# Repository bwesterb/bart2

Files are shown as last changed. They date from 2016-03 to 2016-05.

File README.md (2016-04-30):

Controller for the Bar T2
-------------------------

We replaced the mechanical pressure switch of the Pavoni Bart T2 coffee
machine with two thermometers, three microcontrollers and a raspberry pi.

See `avr/attiny13/ctrl.c` for the firmware of the two microcontrollers
responsible for switching the heater on and off depending on the
temperature.

The third micrcontroller lets the raspberry pi communicate with the
other microcontroller.  Its firmware can be found in `avr/attiny85/mux.c`.

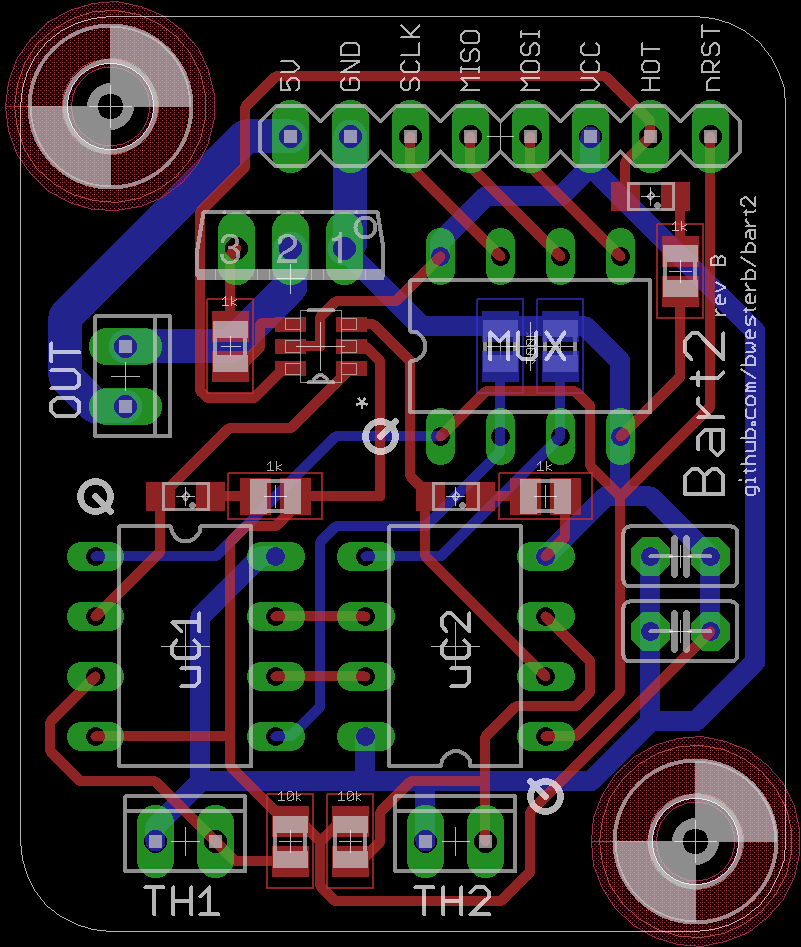
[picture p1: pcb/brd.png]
pcb


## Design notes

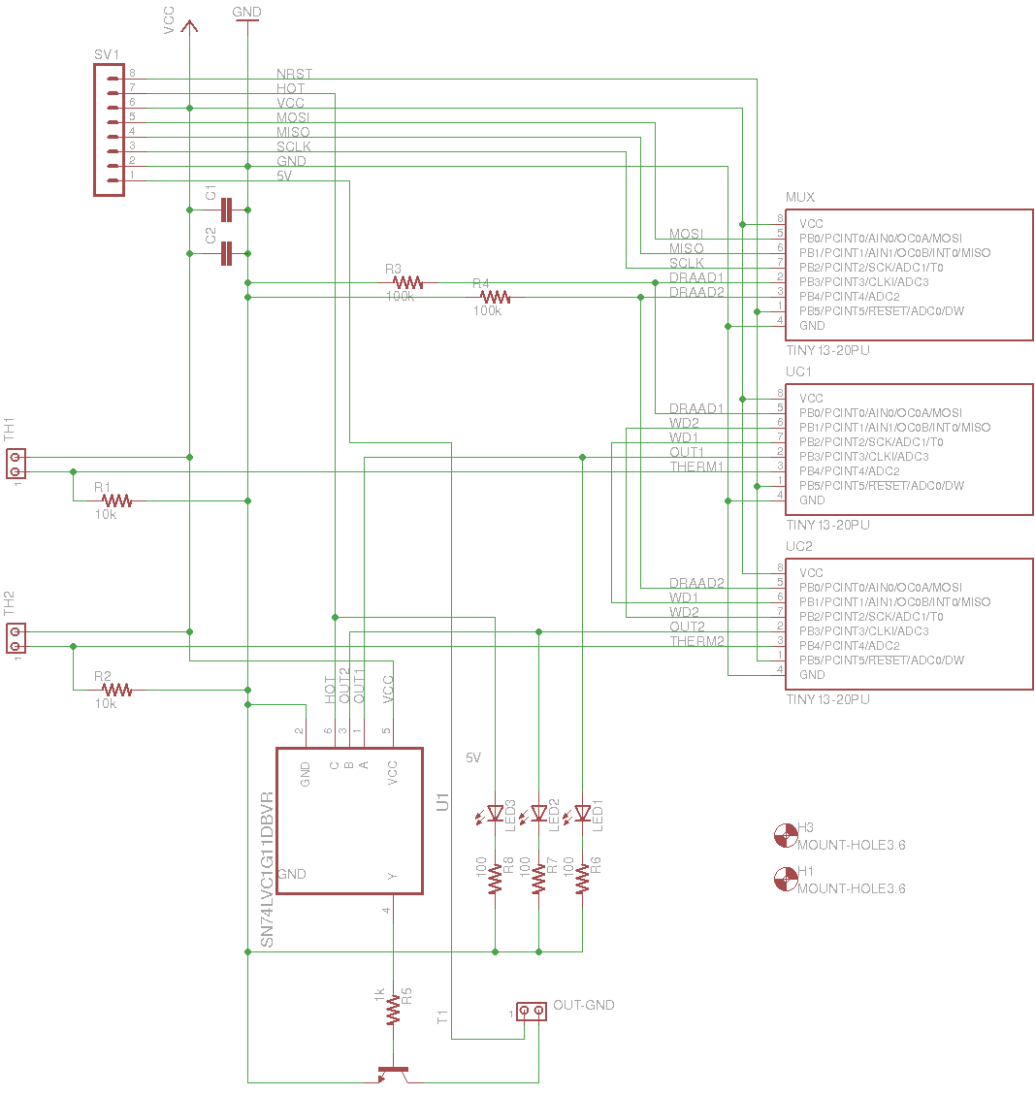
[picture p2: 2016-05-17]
pcb/sch.png

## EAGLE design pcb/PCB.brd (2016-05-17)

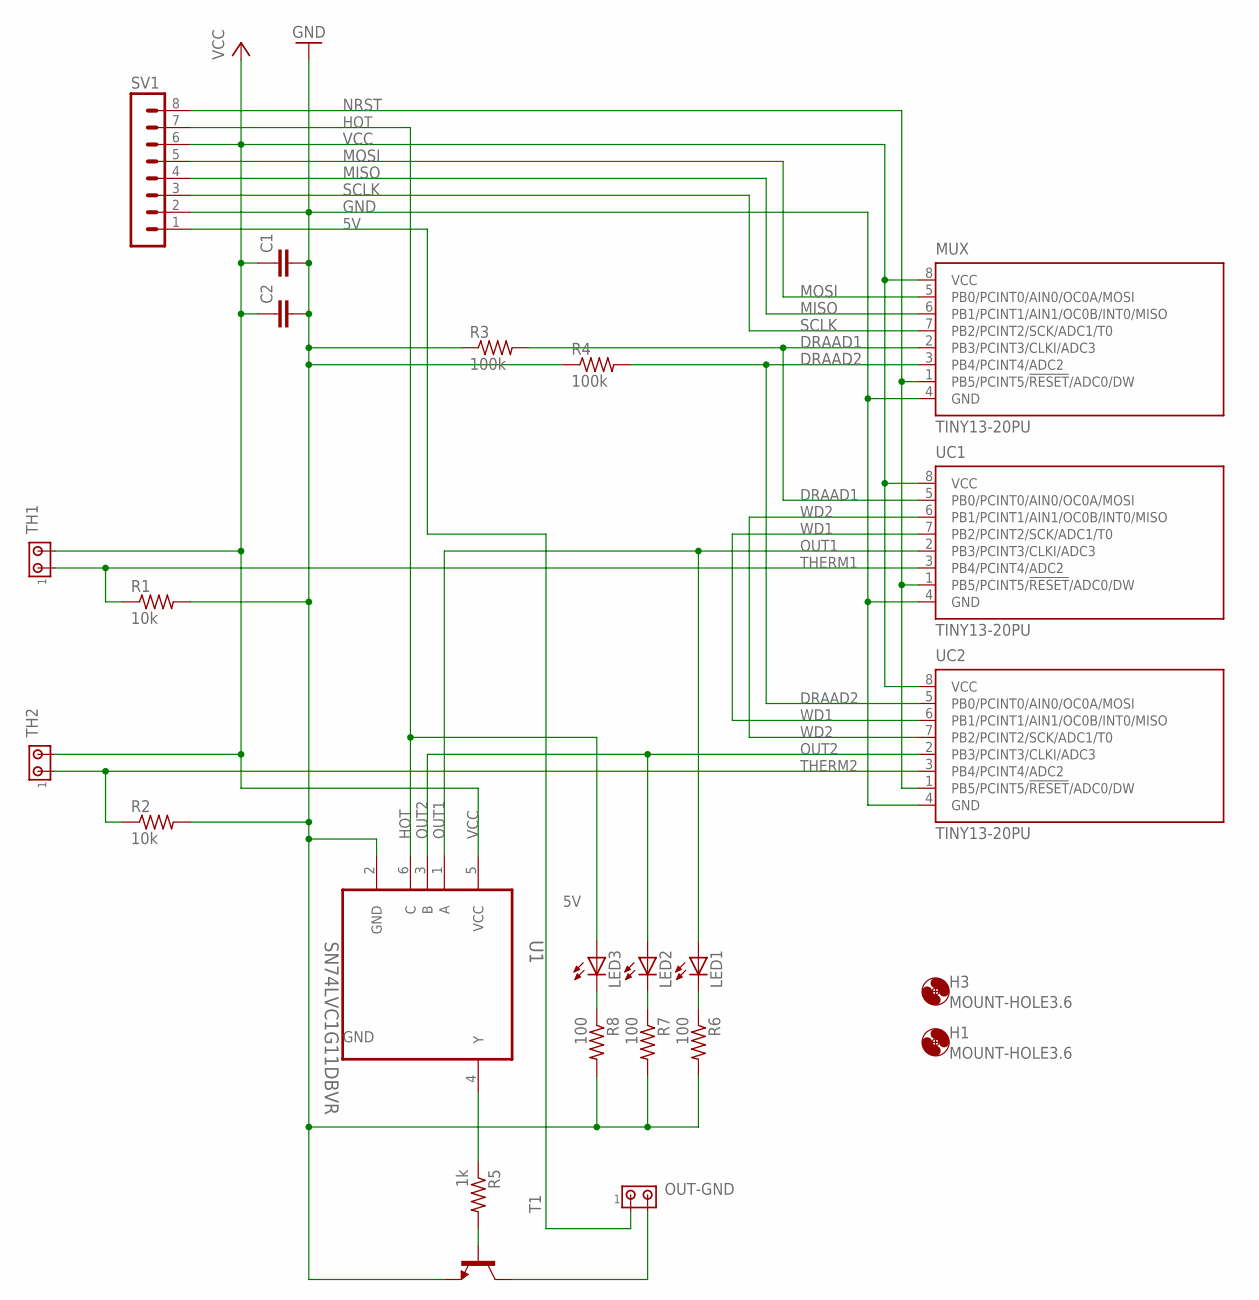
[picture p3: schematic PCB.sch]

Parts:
C1, C2: C2.5/2; C2.5-2
H1, H3: MOUNT-HOLE3.6; 3,6
LED1, LED2, LED3: LEDSML0805; SML0805
MUX: TINY13-20PU; DIL08
OUT-GND: MTA02-100; 10X02MTA
R1, R2: 10k; R0805
R3, R4: 100k; R0805
R5: 1k; R0805
R6, R7, R8: 100; R0805
SV1: MA08-1
T1: -NPN-TO126V; TO126V
TH1, TH2: MTA02-100; 10X02MTA
U1: SN74LVC1G11DBVR; SOT95P280X145-6N
UC1, UC2: TINY13-20PU; DIL08

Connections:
5V: OUT-GND.1, SV1.1
DRAAD1: MUX.2 (PB3/PCINT3/CLKI/ADC3), R3.2, UC1.5 (PB0/PCINT0/AIN0/OC0A/MOSI)
DRAAD2: MUX.3 (PB4/PCINT4/ADC2), R4.2, UC2.5 (PB0/PCINT0/AIN0/OC0A/MOSI)
GND: C1.2, C2.2, MUX.4 (GND), R1.2, R2.2, R3.1, R4.1, R6.2, R7.2, R8.2, SV1.2, T1.1 (E), U1.2 (GND), UC1.4 (GND), UC2.4 (GND)
HOT: LED3.A, SV1.7, U1.6 (C)
MISO: MUX.6 (PB1/PCINT1/AIN1/OC0B/INT0/MISO), SV1.4
MOSI: MUX.5 (PB0/PCINT0/AIN0/OC0A/MOSI), SV1.5
unnamed: OUT-GND.2, T1.2 (C)
unnamed: LED3.C, R8.1
unnamed: R5.1, U1.4 (Y)
unnamed: R5.2, T1.3 (B)
unnamed: LED2.C, R7.1
unnamed: LED1.C, R6.1
NRST: MUX.1 (PB5/PCINT5/!RESET!/ADC0/DW), SV1.8, UC1.1 (PB5/PCINT5/!RESET!/ADC0/DW), UC2.1 (PB5/PCINT5/!RESET!/ADC0/DW)
OUT1: LED1.A, U1.1 (A), UC1.2 (PB3/PCINT3/CLKI/ADC3)
OUT2: LED2.A, U1.3 (B), UC2.2 (PB3/PCINT3/CLKI/ADC3)
SCLK: MUX.7 (PB2/PCINT2/SCK/ADC1/T0), SV1.3
THERM1: R1.1, TH1.1, UC1.3 (PB4/PCINT4/ADC2)
THERM2: R2.1, TH2.1, UC2.3 (PB4/PCINT4/ADC2)
VCC: C1.1, C2.1, MUX.8 (VCC), SV1.6, TH1.2, TH2.2, U1.5 (VCC), UC1.8 (VCC), UC2.8 (VCC)
WD1: UC1.7 (PB2/PCINT2/SCK/ADC1/T0), UC2.6 (PB1/PCINT1/AIN1/OC0B/INT0/MISO)
WD2: UC1.6 (PB1/PCINT1/AIN1/OC0B/INT0/MISO), UC2.7 (PB2/PCINT2/SCK/ADC1/T0)

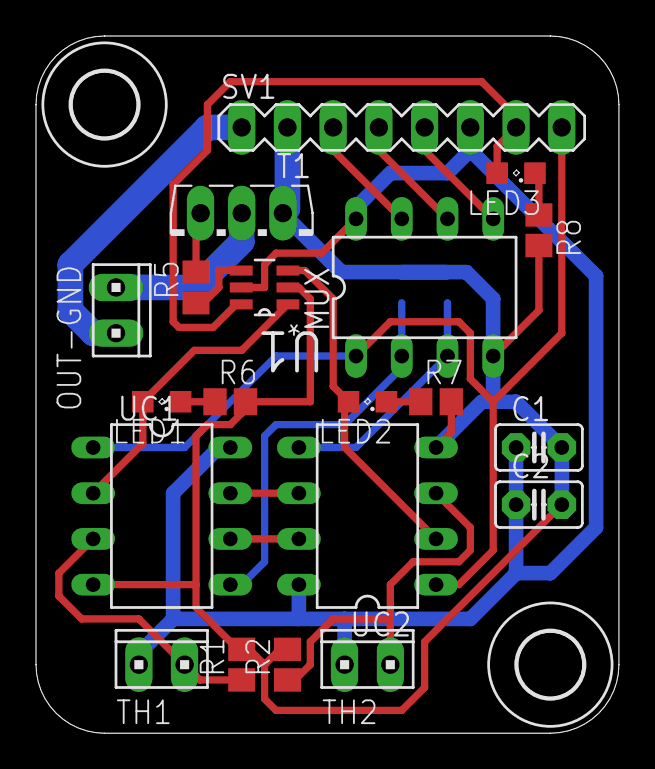
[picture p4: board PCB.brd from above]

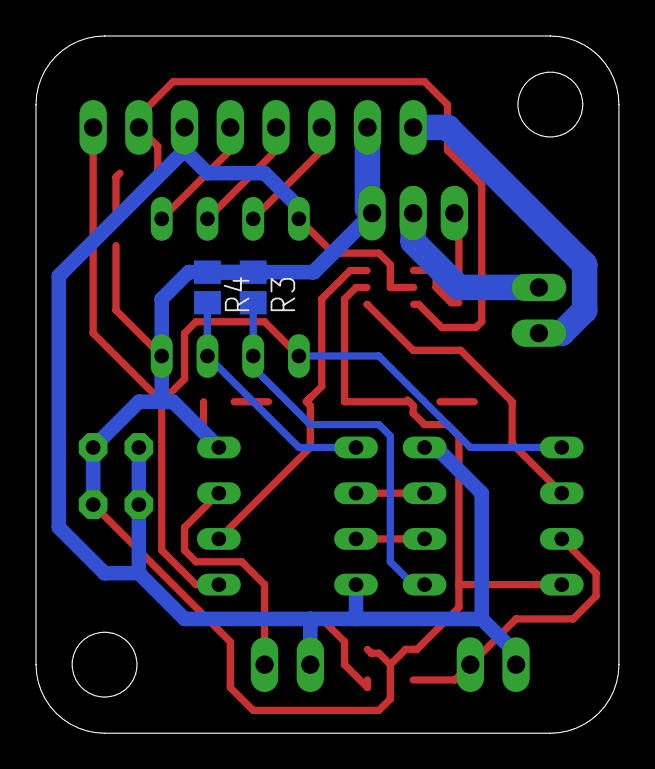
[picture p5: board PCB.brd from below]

Board: 2 copper layers, 32.4 x 38.7 mm, 24 parts (2 on the bottom side), 22 nets.

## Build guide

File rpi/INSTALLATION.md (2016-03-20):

The configuration of the rpi is managed using salt. This is how to bootstrap it.

1. Write raspbian lite to SD-card
2. Boot rPi and log in with user `pi` (password `raspberry`)
3. Change `/etc/wpa_supplicant/wpa_supplicant.conf` and run
   `systemctl restart networking` to get WiFi.
4. Run `raspi-config` and check everything.  Do not forget to enable SSH and SPI
   *and* to disable Serial login.  `reboot`.
5. Login via SSH.  Set `authorized_keys` on root. Delete the pi user. Scramble
   root password.
6. `apt-get update`
7. `apt-get install git salt-minion`
8. set `file_client: local` and `state_verbose: False` in `/etc/salt/minion`
9. `cd srv && git clone git://github.com/bwesterb/bart2`
10. `ln -s /srv/bart2/rpi/salt /srv/salt`
11. `salt-call state.highstate`

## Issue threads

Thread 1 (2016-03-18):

attiny13 frequency seems to be ~1.17MHz at 3.3V

bwesterb, 2016-03-18:
What is it exactly?  Does it vary?  Can we stabilise it?

bwesterb, 2016-03-19:
Default is 1.2MHz.  See §6.2.2 of docs.

bwesterb, 2016-03-22:
Varies quite a bit, actually.  Instead of UART, we'll use SPI, which has an external clock.

Closed 2016-03-19.

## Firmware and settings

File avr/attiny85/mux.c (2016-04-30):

// Firmware for the MUX ATTINY85 microcontroller.
//
// The MUX is connected to the rPi and the two microcontrollers that actually
// measure the temperature and determine whether to switch on the heaters
// of the coffee machine.
//
// The job of the MUX uC is to transfer messages to and from the two
// other uCs to the rPi.
//
// The MUX is connected to the rPi using a 3-wire SPI connection in mode 01
// with a baudrate of ~10kHz.
//
// There is a single wire from the MUX to each of the other uCs.  With this
// single wire the uC and the MUX can communicate in half-duplex using a
// variation on the "one-wire protocol", we call "draad".  See XXX
//
// XXX send status

#include "common.h"

// Pinout
#define PIN_SPI_MOSI   DDB0
#define PIN_SPI_MISO   DDB1
#define PIN_SPI_CLOCK  DDB2
#define PIN_DRAAD1     DDB3
#define PIN_DRAAD2     DDB4

register unsigned long spi_tx_buffer asm("r10"); // r10, r11, r12, r13
register byte spi_tx_buffer_size asm("r14");    // XXX only need 5 bits

volatile unsigned long draad_tx_buffer[2] = {0,0};
volatile byte draad_tx_buffer_size[2] = {0,0};

unsigned long draad_rx_buffer[2] = {0,0};
byte draad_rx_buffer_size[2] = {0,0};


struct status {
    byte draad_tx_overflow : 1;
    byte spi_rx_overflow : 1;
};

register struct status status asm("r15");

#define SPI_RX_BUFFER_MAX   8       // max size of the SPI rx buffer
byte spi_rx_buffer[SPI_RX_BUFFER_MAX];
byte spi_rx_buffer_size asm("r16");
byte spi_rx_buffer_offset asm("r17");

void main(void) __attribute__ ((noreturn));

void main(void)
{
    byte spi_frame_body_bits_to_read = 0;
    byte spi_frame_body_size = 0;
    long spi_frame_body;
    byte spi_frame_who;

    full_speed_clock();

    spi_tx_buffer = 0;
    spi_tx_buffer_size = 0;

    spi_rx_buffer_size = 0;
    spi_rx_buffer_offset = 0;

    status.draad_tx_overflow = 0;
    status.spi_rx_overflow = 0;

    // Set up pins and interrupts for SPI.
    DDRB |= _BV(PIN_SPI_MISO);  // MISO (for SPI) is output

    // Set up universal serial interface
    USICR |= _BV(USIWM0) | _BV(USICS1) | _BV(USICS0) // SPI mode 01
          | _BV(USIOIE);   // with overflow interrupt.

    sei();  // enable interrupts

    // We will loop and either
    //  (1) poll the first uC,
    //  (2) poll the second uC,
    //  (3) prepare the data to be send over SPI or
    //  (4) parse the data we received over SPI.
    // We process the SPI data in the main loop such that we don't spend
    // too much time in interrupt handlers, which would mess with the timing
    // on the draad.

    byte who = 0; // which uC is being polled?

    for(;;) {
        who = 1 - who;
        
        // Interpret SPI rx buffer if it's not empty
        while (spi_rx_buffer_size > 0) {
            byte spi_byte_received;

            ATOMIC_BLOCK(ATOMIC_FORCEON)
            {
                spi_byte_received = spi_rx_buffer[spi_rx_buffer_offset];
                spi_rx_buffer_size--;
                spi_rx_buffer_offset = (spi_rx_buffer_offset + 1)
                                                % SPI_RX_BUFFER_MAX;
            }

            // Are we in the middle of receiving a frame?
            if (spi_frame_body_bits_to_read > 0) {
                if (spi_frame_body_bits_to_read < 8)
                    spi_frame_body_bits_to_read = 0;
                else
                    spi_frame_body_bits_to_read -= 8;
                spi_frame_body |= (spi_byte_received
                                    << spi_frame_body_bits_to_read);

                if (spi_frame_body_bits_to_read > 0)
                    continue;

                // We received the whole frame.  Send it over draad.
                if (spi_frame_who > 1)
                    continue;

                // Check for overflow
                if (draad_tx_buffer_size[spi_frame_who]
                            + spi_frame_body_size > 32) {
                    status.draad_tx_overflow = 1;
                    continue;
                }

                // Again note that we can't be interrupted here.
                draad_tx_buffer[spi_frame_who] |= (spi_frame_body
                                        << draad_tx_buffer_size[spi_frame_who]);
                draad_tx_buffer_size[spi_frame_who] += spi_frame_body_size;
                continue;
            }

            // Either there is no frame, or we are at the start of a frame.
            // Is there a frame?
            if (!(spi_byte_received & 128))
                continue;  // there is no frame

            // Start of a new frame.  Parse the header
            spi_frame_body_size = (spi_byte_received >> 2) & 31;
            spi_frame_body_bits_to_read = spi_frame_body_size;
            spi_frame_who = (spi_byte_received) & 3;
            spi_frame_body = 0;
        }

        // Fill SPI tx buffer if it's empty
        if (spi_tx_buffer_size == 0 && draad_rx_buffer_size[who] > 0) {
                byte n_bits_to_send = draad_rx_buffer_size[who];
                if (n_bits_to_send > 24)
                    n_bits_to_send = 24;
            ATOMIC_BLOCK(ATOMIC_FORCEON)
            {
                spi_tx_buffer = 128 | (n_bits_to_send << 2) | who
                                  | (draad_rx_buffer[who] << 8);
                spi_tx_buffer_size = 8 + n_bits_to_send;
            }
            draad_rx_buffer_size[who] -= n_bits_to_send;
            draad_rx_buffer[who] >>= n_bits_to_send;
        }

        byte pin = who == 0 ? PIN_DRAAD1 : PIN_DRAAD2;

        if (draad_tx_buffer_size[who] > 0) {
            byte to_send;

            // Fetch the bit to send
            ATOMIC_BLOCK(ATOMIC_FORCEON)
            {
                to_send = draad_tx_buffer[who] & 1;
                draad_tx_buffer[who] >>= 1;
                draad_tx_buffer_size[who]--;
            }

            // Send the bit
            PORTB |= _BV(pin);
            if (to_send)
                _delay_us(DRAAD_DELAY * 3 - DRAAD_PULLDOWN_TIME);
            else
                _delay_us(DRAAD_DELAY * 2 - DRAAD_PULLDOWN_TIME);

            PORTB &= ~_BV(pin);
            if (to_send)
                _delay_us(DRAAD_DELAY * 1 + DRAAD_PULLDOWN_TIME);
            else
                _delay_us(DRAAD_DELAY * 2 + DRAAD_PULLDOWN_TIME);

            continue;
        }

        // Is our buffer empty enough to receive something from the uC?
        if (draad_rx_buffer_size[who] == 32)
            continue;

        byte received = 0;
        PORTB |= _BV(pin);
        _delay_us(DRAAD_DELAY - DRAAD_PULLDOWN_TIME);

        PORTB &= ~_BV(pin);
        _delay_us(DRAAD_DELAY + DRAAD_PULLDOWN_TIME);

        if (!(PINB & _BV(pin))) {
            _delay_us(DRAAD_DELAY * 2);
            continue;  // No reply
        }

        _delay_us(DRAAD_DELAY);
        if (PINB & _BV(pin))
            received = 1;

        draad_rx_buffer[who] |= (received << draad_rx_buffer_size[who]);
        draad_rx_buffer_size[who]++;
        _delay_us(DRAAD_DELAY);
    }
}

// Interrupt handlers.

// Called when the USI unit just received data over SPI.  We store the data in
// a buffer.  Also we provide the USI unit with the byte to send for the next
// cycle.
ISR(USI_OVF_vect)
{
    if (spi_rx_buffer_size == SPI_RX_BUFFER_MAX) {
        status.spi_rx_overflow = 1;
    } else {
        byte i = (spi_rx_buffer_offset + spi_rx_buffer_size
                        ) % SPI_RX_BUFFER_MAX;
        spi_rx_buffer[i] = USIBR;
        spi_rx_buffer_size++;
    }

    if (spi_tx_buffer_size == 0) {
        USIDR = 0;
        goto done;
    }

    USIDR = spi_tx_buffer & 255;  // next byte to send

    spi_tx_buffer >>= 8;

    if (spi_tx_buffer_size < 8)
        spi_tx_buffer_size = 0;
    else
        spi_tx_buffer_size -= 8;

done:
    USISR |= _BV(USIOIF);  // clear interrupt
}

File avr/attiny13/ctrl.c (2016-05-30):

// Firmware for the uC1 and uC2 ATTINY13 microcontroller.
//
// Each of the uCs measures the temperature of the kettle and decides
// whether to turn on the boiler.  The uCs are connected to a third
// uC, the MUX, via a single wire.  See XXX
//
// XXX check whether temperature increase is within reasonable bounds when
//      the heater is turned on --- this is to prevent the boiler from heating
//      an (half-)empty boiler.

#include "common.h"

// Pinout
#define PIN_DRAAD      DDB0
#define PIN_WATCH_IN   DDB1
#define PIN_WATCH_OUT  DDB2
#define PIN_GO         DDB3
#define PIN_THERM      DDB4

// Limits on tempearture
#define TEMP_TARGET         790     // Heat if temp is below this
#define TEMP_LOWER_BOUND    26      // go into error mode if temp is below this
#define TEMP_UPPER_BOUND    980     // go into error mode if temp is above this

// We add 32 measurements and to get a neat average.  adc_accum cotains
// the partial sums of the current measurements and adc_cnt the amount we
// have performed.
register unsigned int adc_accum asm("r2");  // r2, r3
register byte adc_cnt asm("r4");
register byte watch_in_changed asm("r5");

struct status {
    unsigned int temperature : 10;
    byte heating : 1;
    byte ok : 1;
    byte temp_way_too_low : 1;
    byte temp_way_too_high : 1;
    byte other_uC_not_responding : 1;
};

struct status status;

void main(void) __attribute__ ((noreturn));

void main(void)
{
    full_speed_clock();

    // Initialize variables
    unsigned long draad_tx_buffer = 0;
    byte draad_tx_buffer_size = 0;

    adc_accum = 0;
    adc_cnt = 0;
    watch_in_changed = 0;

    status.heating = 0;
    status.ok = 1;
    status.temperature = 0;
    status.temp_way_too_low = 0;
    status.temp_way_too_high = 0;
    status.other_uC_not_responding = 0;

    // Set up watch timer (~18Hz)
    TCCR0B |= _BV(CS00) | _BV(CS02);  // enable clock --- prescale by 1024
    TIMSK0 |= _BV(TOIE0);        // enable clock overflow interrupt

    // Set up pins and interrupts for SPI.
    DDRB |= _BV(PIN_WATCH_OUT);  // Set WATCH_OUT to an output pin
    DDRB |= _BV(PIN_GO);         // Set GO to an output pin

    // Enable the ADC
    ADCSRA |= (1 << ADPS1) | (1 << ADPS2) | (1 << ADEN) | (1 << ADIE);
    ADMUX |= (1 << MUX1);  // ADC2 (PB4)

    PCMSK |= 1 << PCINT1;   // interrupt on WATCH_IN
    GIMSK |= 1 << PCIE;     // enable pin-change interrupts

    sei();  // enable interrupts

    ADCSRA |= (1 << ADSC);  // start first ADC conversion

    PINB |= _BV(PIN_WATCH_OUT);  // let other uC know the ADC is running

    // XXX make protocol on draad more flexible.  I.e. to set THERM_* runtime.
    for (;;) {
        // Wait until the mux pulls the draad high
        while (!(PINB & _BV(PIN_DRAAD)));

        _delay_us(DRAAD_DELAY * 1.25);

        // Is master sending a write(0) or write(1)?
        // If so, see what the master is writing.
        if (PINB & _BV(PIN_DRAAD)) {
            byte received = 0;

            _delay_us(DRAAD_DELAY * 1.50);

            if (PINB & _BV(PIN_DRAAD))
                received = 1;

            // XXX here we could handle more complex incoming messages ---
            // for now we'll just send our status message everytime we
            // get any incoming bit 1.
            if (draad_tx_buffer_size == 0 && received) {
                draad_tx_buffer = *((unsigned long*)(&status));
                draad_tx_buffer_size = 16;
            }

            while (PINB & _BV(PIN_DRAAD));

            _delay_us(DRAAD_DELAY * 0.25);
            continue;
        }

        // Master sends a read, send a bit if we have one to send.
        if (draad_tx_buffer_size == 0) {
            _delay_us(DRAAD_DELAY * 2.25);
            continue;
        }

        PORTB |= _BV(PIN_DRAAD);

        byte bit = !!(draad_tx_buffer & 1);
        draad_tx_buffer_size--;
        draad_tx_buffer >>= 1;

        if (bit)
            _delay_us(DRAAD_DELAY * 2 - DRAAD_PULLDOWN_TIME);
        else
            _delay_us(DRAAD_DELAY - DRAAD_PULLDOWN_TIME);

        PORTB &= ~_BV(PIN_DRAAD);
        _delay_us(DRAAD_DELAY * 0.25 + DRAAD_PULLDOWN_TIME);
    }
}

// ADC conversion is ready interrupt.
// XXX is the interrupt handler fast enough to not disturb draad communication?
ISR(ADC_vect)
{
    adc_accum += ADCW;
    adc_cnt++;

    if (adc_cnt == 32) {
        unsigned int temp = adc_accum >> 5;

        PINB |= _BV(PIN_WATCH_OUT);  // let other uC know the ADC is running

        status.temperature = temp;
        adc_accum = 0;
        adc_cnt = 0;

        if (temp <= TEMP_LOWER_BOUND) {
            status.ok = 0;
            status.temp_way_too_low = 1;
            status.heating = 0;
            PORTB &= ~_BV(PIN_GO);
        } else if (temp >= TEMP_UPPER_BOUND) {
            status.ok = 0;
            status.heating = 0;
            status.temp_way_too_high = 1;
            PORTB &= ~_BV(PIN_GO);
        } else if (!status.ok) {
        } else if (temp < TEMP_TARGET) {
            PORTB |= _BV(PIN_GO);
            status.heating = 1;
        } else  {
            PORTB &= ~_BV(PIN_GO);
            status.heating = 0;
        }
    }

    ADCSRA |= (1 << ADSC);
}

// Watchdog pin changed value.
ISR(PCINT0_vect)
{
    watch_in_changed = 1;
}

// Timer overflowed
ISR(TIM0_OVF_vect)
{
    // XXX grace period during start-up?
    if (!watch_in_changed) {
        // Other uC did not respond in time
        status.ok = 0;
        status.heating = 0;
        status.other_uC_not_responding = 1;
        PORTB &= ~_BV(PIN_GO);
        return;
    }

    watch_in_changed = 0;
}

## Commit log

2016-03-22 spitherm: test firmware that measures voltage on pin and sends over SPI
2016-03-22 Adapt blink just to blink LED and left-over pin
    With blink we can measure the frequency of the uC
2016-03-25 Added pcb
    [PCB.brd, PCB.sch]
2016-03-25 Added pictures of pcb
2016-03-28 Complete and fix mux. Decrease size.
    [mux.c]
2016-03-29 PCB image
2016-04-09 avr: add test for AVR timer
2016-04-09 ctrl: fix timer code
    [ctrl.c]
2016-04-10 avr: add mirror test fw to determine 0 -> 1 voltage
2016-04-16 mux: decode SPI frames
2016-04-17 attiny85: SPI test
2016-04-30 Two more bugs in the mux
    [mux.c]
2016-04-30 work on bart2d: spi
2016-05-01 more work on the spi interface
2016-05-10 Updated pcb
    [PCB.brd, PCB.sch]
2016-05-17 changes Muxi SPI speedHz to a power of 2 to support RPI mark 1
2016-05-30 ctrl: bounds for 1kOhm resistor
